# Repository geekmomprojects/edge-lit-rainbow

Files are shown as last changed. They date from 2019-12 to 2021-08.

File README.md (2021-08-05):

# Edge-Lit Rainbow
Updated code and design files for Edge Lit Rainbow project in Make: Vol. 69

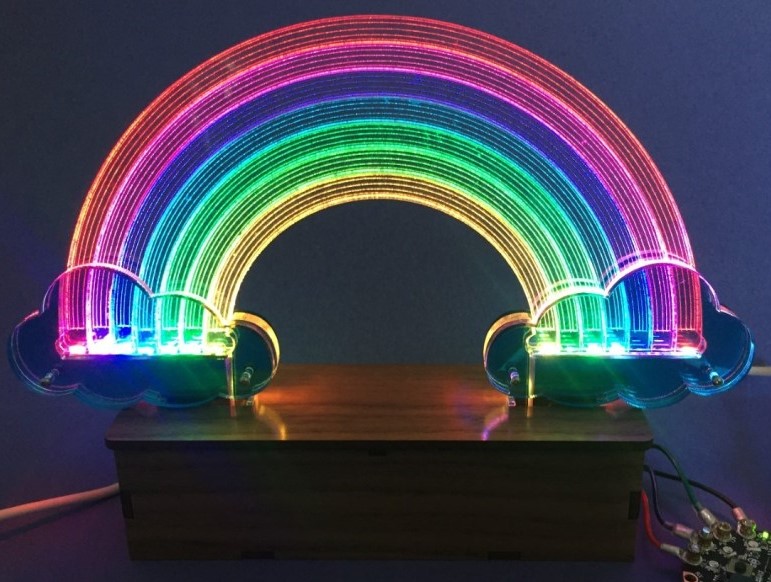
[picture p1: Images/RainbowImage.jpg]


When connected to WiFi and running the included Arduino code, the controller can connect to OpenWeatherMap to retrieve current temperature and weather conditions. If the conditions are sucessfully downloaded, every 30 seconds, the rainbow will display a solid color that maps to the current temperature, using the spectrum shown below:



The original instructions connected the rainbow to an Adafruit Huzzah ESP8266 microcontroller as shown below:

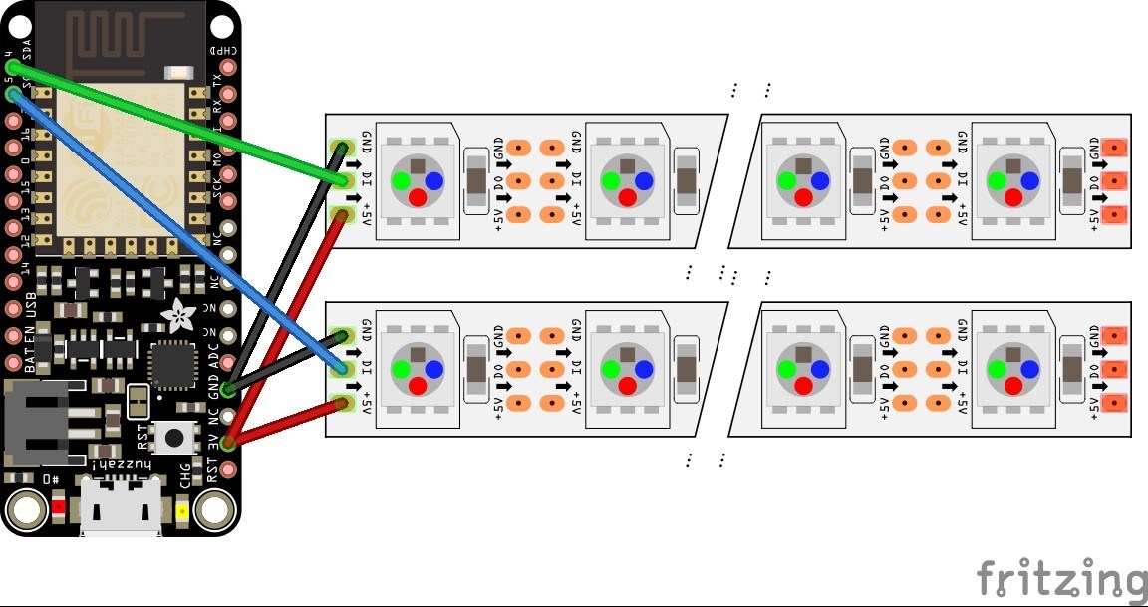
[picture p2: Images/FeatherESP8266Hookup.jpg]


The rainbow may now be connected to an ESP32 or ESP8266 controller, with an optional push button to allow it to enter configuration mode:

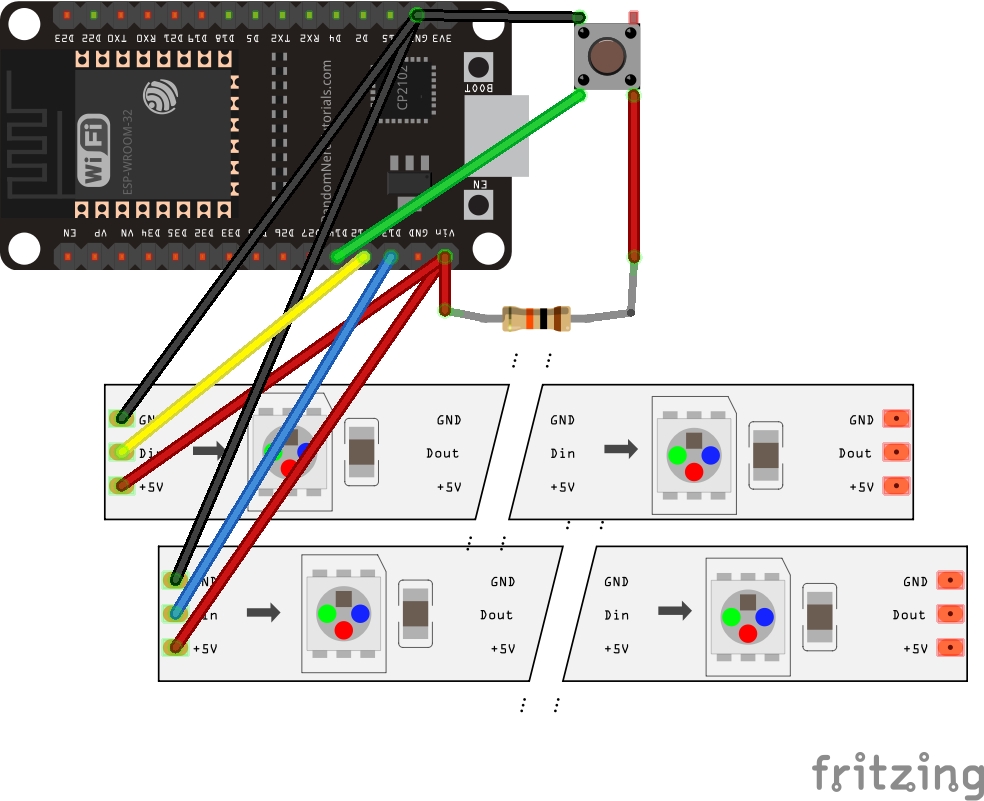
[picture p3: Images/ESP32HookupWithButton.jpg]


CircuitPython code is also included to allow the Rainbow to be connected to an Adafruit Circuit Playground Express in an interactive mode:

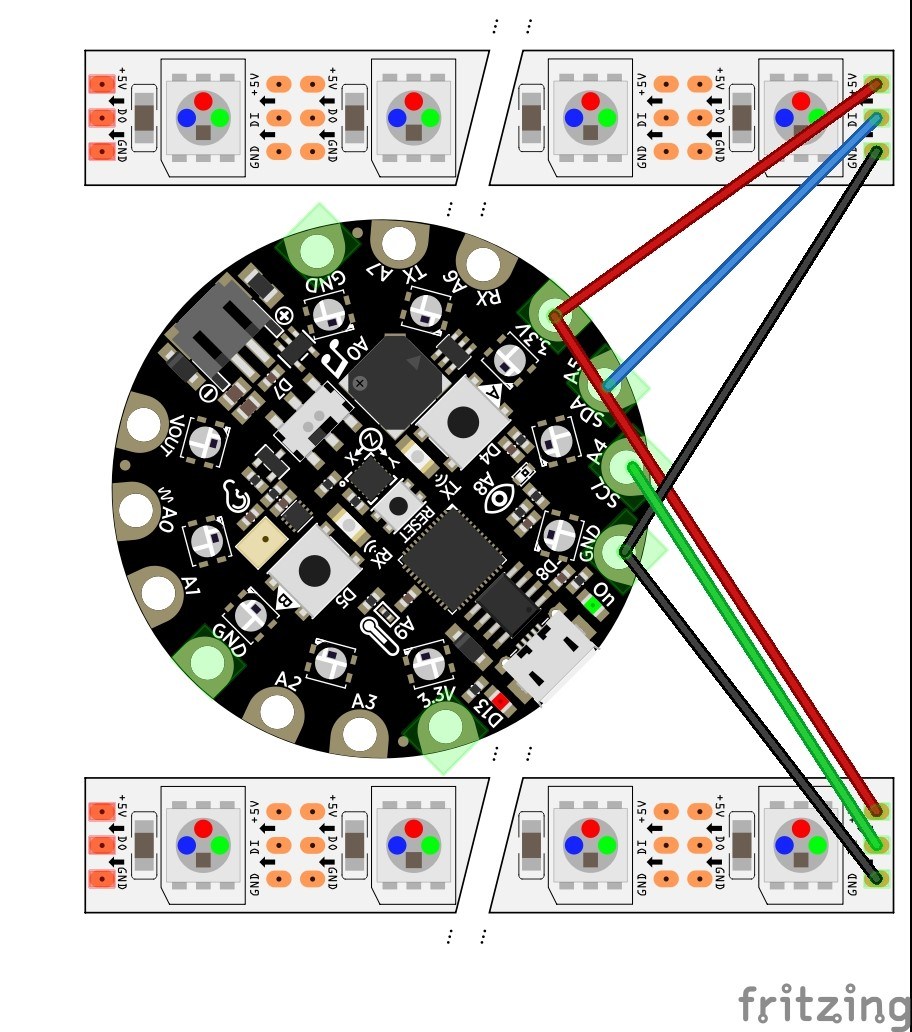
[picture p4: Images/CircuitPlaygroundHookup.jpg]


# Configuration Mode

While it is attempting to connect to WiFi, the rainbow will cycle through lighting up each arc until it has successfully connected or until it enters configuration mode. If it connects successfully, it will display cycling rainbow pattern. When it enters configuration mode, all arcs of the rainbow will pulse red until the WiFi connection is configured, or until 90 seconds has passed. After 90 seconds, the normal rainbow pattern will start to display.

When running on an ESP32 or ESP8266 with the supplied Arduino code, the rainbow will enter configuration mode automatically on startup if it cannot connect to WiFi, either because it doesn't have stored SSID/Password or because the stored SSID/Password don't connect. You can also force the ESP into configuration mode at startup by grounding the button pin (easiest if you physically connect a button to the pin).

Once it is in configuration mode, you can configure the connection parameters by connecting to the local access point named "RainbowConnection". 

Currently, you may find additional information about configuring the connection parameters here: <a href="http://brightwearables.com/rainbowconnect/">http://brightwearables.com/rainbowconnect/</a>

# Update - July 19, 2020

The following changes have been added to the Arduino code:
- The code now runs on ESP32 as well as ESP8266 boards
- Code is added to support an optional push putton which starts the program in "Configuration Mode". In Configuration mode, the ESP board boots as a WiFi access point named "RainbowConnection". Logging int access point allows the user to configure the board to connect to local WiFi.
- The OpenWeatherMap LocationID and AppID are stored in spiffs and can be set through the Access Point when the ESP is in Configuration Mode

# Update - August 6, 2021

The code has been streamlined a bit and successfully tested on both an ESP8266 and ESP32
- The Arduino code has been reconfigured to remove any dependence on external OpenWeatherMap access libraries, and the Arduino sketch is now contained in a single file.
- The Arduino library dependencies have changed. See the comments at the top of the sketch to find which libraries you will need for your board
- The pin for the LED strips and buttons have changed. Look for the variables LED_PIN_LEFT, LED_PIN_RIGHT and BUTTON_PIN to find/change their values

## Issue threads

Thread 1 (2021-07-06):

Finding Libraries?

gallaugher, 2021-07-06:
Sorry to trouble you. I must be missing something basic. Am running on an Adafruit Huzzah32, and "Adafruit ESP32 Feather" is installed & serial port seems to be recognized properly. Am using Arduino IDE 1.8.15.

Comments list the libraries that are required & that can be found in the Arduino Library Manager, but I can't seem to locate:
**ESP8266WiFi**, **ESP8266HTTPClient**, and **JsonListener**.
Is there an Additional Board Manager URL I need to enter to find these, or am I skipping another key step?

When I run & compile (noting I haven't installed the three libraries above), I get the error:
**LITTLEFS.h: No such file or directory**
Found "LittleFS_esp32" in Arduino Library Manager, installed that, the error above went away, but then encountered:
**"ESP8266WebServer.h: No such file or directory"**
When searching "ESP8266WebServer" under basic Arduino Library Manager configuration, five libraries come up, but none are named "ESP8266WebServer".

API key & location should be properly set once these issues are resolved. Thanks for your work on this great project & for taking the time to respond.

geekmomprojects, 2021-07-06:
Hi,

Sorry it’s causing you difficulty. The ESP8266WiFi & ESP8266HTTPClient, should show up if you have the following in your Additional Manager URLs: http://arduino.esp8266.com/stable/package_esp8266com_index.json. Hopefully that will solve your ESP8266WebServer issues as well.

The JSON listener library is in the library manager if you filter the “Manage Libraries” window with “json streaming parser”.

Let me know if you’re still having problems.

Best,
Debra

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

gallaugher, 2021-07-07:
Thanks for your kind response & your great work. I think I've hunted down some additional steps that will make things work on the Huzzah32. Detailed what I did below, but you know WAY more about Arduino than I do, and this is your brilliant creation, so apologies if I've got something wrong & just goofed.

For some reason, when I added the URL in Arduino preferences:
http://arduino.esp8266.com/stable/package_esp8266com_index.json
I still couldn't find the esp8266 in Manage Libraries...
Wasn't sure this is what I needed for the the Huzzah32, but I found that I could comment out:
  #include <ESP8266WebServer.h>
and replace this with
  #include <WebServer.h>
and when I ran this, I was able to get everything to work except the LEDs: Rainbow Connection allowed setup to my local WiFi, then in the Serial Monitor I saw proper fetching & printing weather for my location.
unfortunately my LEDs weren't showing. Since they were working with the CPX (I used your tip on soldering the JST connectors for quick swap-out. Great advice - I bought a bunch of connectors to do this in future projects), I thought I had a soldering / wire problem on the Huzzah32 side. But I saw this wasn't the case when I broke out an old Huzzah (the older 8266) and wrote a simple sketch which I thought would light up the strips. Struggled to figure out why code on the other board wasn't working, then consulted the pinouts & saw they were different! Changing the LED_PIN_RIGHT & _LEFT seems to have fixed this. I think this is because the SDA and SCL pins are different numbers on those two boards.

Sorry I didn't take better notes when trouble-shooting, but I *think* this is what works for to get the project to function on a Huzzah32:

Use WebServer.h instead of ESP8266WebServer.h (which I *think* is in ESP_WiFiManager, which I found & added when searching for Libraries in the Arduino's "Manager Libraries...").
> Commented out: #include <ESP8266WebServer.h>
> Replaced with: #include <WebServer.h> // all other code related to these libraries seemed to work w/o additional modification.

Replace the LED_PIN values to conform to Huzzah32
> #define LED_PIN_RIGHT 23 // <- pin for SDA on Huzzah32
> #define LED_PIN_LEFT 22 // <- pin for SCL on Huzzah32

I may have also had to track down some additional libraries at other points. I was struggling to find LittleFS, but eventually found it. I have FS and LittleFS_esp32 in my Include Library menu. Again, sorry I didn't take better notes during the troubleshooting.

Also: I tried running the updated RainbowWeatherStation code on an older Huzzah with the 8266, but it failed when hitting the first line:
#include <vfs_api.h>
Unsure if this is something specific to ESP32. I didn't go back & try to re-work the code & fully wire the 8266, but maybe just drop that in the if block where you check if the ESP32 is running?

Finally - am I correct in assuming whenever the build is powered down that Wi-Fi needs to b re-set? When I moved from Huzzah connected to my Mac to a separate power connection for the build, I needed to re-establish Wi-Fi with Rainbow connection despite being on the same WiFi network. My assumption based on this is that there's no flash storage or code to save these parameters on the Huzzah32. Didn't go through the code to see if code is, in fact, there & it's just not working on Huzzah32.

While I definitely struggled getting all this to work, that process is good for me since if I run into problems before my students, hopefully I can guide them through a solution having seen this before. I now know to check pinouts & not assume SCL SDA pins have the same numbers on different boards (sound like I'm diagnosing this right?). Your project really is a beautiful build. Thanks for putting this together & sharing your work!
John

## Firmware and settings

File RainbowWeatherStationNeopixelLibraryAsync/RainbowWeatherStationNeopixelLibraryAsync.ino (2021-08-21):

/************************************************************************************
 * The RainbowWeatherStation sketch is adapted from Adafruit's esp8266 weather station 
 * (https://github.com/adafruit/esp8266-weather-station-color) which, in turn, was adapted
 * from ThingPulse's WiFi Color Display Kit (https://docs.thingpulse.com/guides/wifi-color-display-kit/)
 * 
 *                      ************ Required Libraries ************
 *                      
 * The following libraries are required for this application, and are available through the Arduino
 * library manager, regardless of which board you use:
 * 
 *      ESPAsyncTCP.h>           //https://github.com/me-no-dev/AsyncTCP/archive/master.zip
 *      ESPAsyncWebServer.h      // https://github.com/me-no-dev/ESPAsyncWebServer/archive/master.zip
 *      ESPAsyncWiFiManager.h    //https://github.com/alanswx/ESPAsyncWiFiManager/
 *      Adafruit_NeoPixel
 *      ArduinoJson             // v6.0
 *      Ticker                  // The version explicitly for esp8266
 *    
 * The following libraries are specific to the platform you are running the code on:
 * Running on ESP8266 (e.g. Adafruit HUZZAH, Wemos D1 mini): 
 * 
 *      ESP8266WiFi
 *      ESP8266HTTPClient
 *      
 * Running on ESP32 (e.g. DEVKIT V1 or Adafruit HUZZAH32)
 * 
 *      WiFi
 *      HTTPClient
 *      
 *     ************ Getting Weather Information from Open Weather Map ************
 *
 * UPDATE - July 19, 2020. You can now set the Open Weather Map App ID and Location ID in the code
 * directly, or you can set them through the WiFi Manager. They are stored in SPIFFS as WiFiManager
 * custom parameters
 *
 * This code relies on data from OpenWeatherMap (https://openweathermap.org/), a free 
 * online weather service with an easily accessible API. 
 * 
 * To run the RainbowWeatherStation code on your own ESP8266, you must find and set the following two 
 * variables to values you obtain from OpenWeatherMap:
 * 
 * (1) OPEN_WEATHER_MAP_APP_ID - Get an app id by signing up and following the directions from
 * ThingPulse: https://docs.thingpulse.com/how-tos/openweathermap-key/
 * 
 * (2) OPEN_WEATHER_MAP_LOCATION_ID - Go to https://openweathermap.org/find?q= and search for a 
 * location. Go through the result set and select the entry closest to the actual location you want 
 * to display data for. It'll be a URL like https://openweathermap.org/city/2657896. Select the 
 * numbers that form the last part of the URL and assign them to the variable.
 * 
 *    ************ Establishing an Internet Connection with WiFiManager ************
 * 
 * This code uses the WiFiManager library (https://github.com/tzapu/WiFiManager) to manage WiFi connections, 
 * so there is no need to store an SSID/Password in the code directly. When the RainbowWeatherStation code
 * starts running on an ESP8266, the WiFiManager will connect to the last succesfully connected Access Point. 
 * You will see the arcs of the rainbow scrolling in yellow while it is establishing the connection.
 * 
 * If the ESP8266 is unable to connect to the WiFi, the rainbow will flash on and off in red, indicating
 * that your input is needed. WiFiManager creates it's own access point called "RainbowConnection". Connect
 * any WiFi enabled device to the "RainbowConnection" access point, and open a browser. You will be directed
 * to a popup or website that asks you to enter a network SSID and password. These values will be saved
 * on the ESP8266 for the next time you run the code.
 * 
 * 
 *   ************ Interpreting the Weather Display ************
 *    
 *   OpenWeatherMap limits the frequency of calls to its API, so the code checks the weather every
 *   12 minutes. The weather conditions will only start to display after the first successful call 
 *   to the OpenWeatherMap API. Therefore no weather conditions will be displayed for the first 12 
 *   minutes after plugging in the WeatherStationRainbow. If you'd like to simulate particular weather
 *   conditions to see what the display looks like, look for the commented code that says 
 *   "simulate particular weather conditions."
 *    
 *   The Rainbow Weather Station displays a rotating color spectrum on the rainbow arcs.
 *   The rainbow display lasts 30 seconds (you can change this value in the array "animDurations")
 *   When the rainbow animation ends, the rainbow colors will fade into a single solid color which
 *   represents the current temperature. The mapping of the temperature to the rainbow spectrum
 *   is shown in the image "TemperatureSpectrum.png"
 
 *   If the weather forecast calls for high winds, rain, or snow, additional animations will run
 *   after the temperature is displayed. The rainbow will remain the color representing the current
 *   temperature but will exhibit the following patterns:
 *   
 *   High Wind - The intensity of the color will increase and dim on each side alternately
 *   Rain - Raindrops (arcs where the LEDs are dimmed) will drip down the rainbow
 *   Snow - The rainbow arcs will display periodic white flashes to represent snowflakes
 *   
 *   Each of these weather animations will last for about 5 seconds. The duration is specified in the
 *   array "animDurations", which you can change if you'd like.
 * 
*************************************************************************************/


/**The MIT License (MIT)

Copyright (c) 2018 by Daniel Eichhorn - ThingPulse

Permission is hereby granted, free of charge, to any person obtaining a copy
of this software and associated documentation files (the "Software"), to deal
in the Software without restriction, including without limitation the rights
to use, copy, modify, merge, publish, distribute, sublicense, and/or sell
copies of the Software, and to permit persons to whom the Software is
furnished to do so, subject to the following conditions:

The above copyright notice and this permission notice shall be included in all
copies or substantial portions of the Software.

THE SOFTWARE IS PROVIDED "AS IS", WITHOUT WARRANTY OF ANY KIND, EXPRESS OR
IMPLIED, INCLUDING BUT NOT LIMITED TO THE WARRANTIES OF MERCHANTABILITY,
FITNESS FOR A PARTICULAR PURPOSE AND NONINFRINGEMENT. IN NO EVENT SHALL THE
AUTHORS OR COPYRIGHT HOLDERS BE LIABLE FOR ANY CLAIM, DAMAGES OR OTHER
LIABILITY, WHETHER IN AN ACTION OF CONTRACT, TORT OR OTHERWISE, ARISING FROM,
OUT OF OR IN CONNECTION WITH THE SOFTWARE OR THE USE OR OTHER DEALINGS IN THE
SOFTWARE.

See more at https://thingpulse.com
*/
#ifdef ESP32    
  #include <FS.h> // needs to be the first include or it all breaks
#endif
#include <Arduino.h>
  
#define USE_LittleFS
#ifdef USE_LittleFS
  #define SPIFFS LittleFS
  #include <LittleFS.h> 
#else
  #include <SPIFFS.h>
#endif 

#ifdef ESP32
  #include <WiFi.h>
  #include <HTTPClient.h>
#endif

#ifdef ESP8266
  #include <ESP8266WiFi.h>
  #include <ESP8266HTTPClient.h>
#endif


#include <DNSServer.h>            //Local DNS Server used for redirecting all requests to the configuration portal

// You have to explicitly specify false to disable the feature.
#define USE_STATIC_IP_CONFIG_IN_CP          false
#include <ESPAsyncTCP.h>            //https://github.com/me-no-dev/AsyncTCP/archive/master.zip
#include <ESPAsyncWebServer.h>     // https://github.com/me-no-dev/ESPAsyncWebServer/archive/master.zip
#include <ESPAsyncWiFiManager.h>  //https://github.com/alanswx/ESPAsyncWiFiManager/

#include <ArduinoJson.h>

// Ticker class runs callback functions at set intervals
#include <Ticker.h>

//Neopixel library - testing Adafruit Neopixel because FastLED seems to conflict with ESP8266 WiFi
#include <Adafruit_NeoPixel.h>


#ifdef __AVR__
  #include <avr/power.h>
#endif
#define LED_PIN_LEFT       13  //13 on Lolin, 19 on DevKit, 12 on Wemos D1 Mini, 
#define LED_PIN_RIGHT      12  //12 on Lolin, 18 on DevKit, 14 on Wemos D1 Mini, 

#define NUM_LEDS_PER_STRIP  7
#define RAINBOW_INCREMENT   // Hue increment between arcs of the rainbow

// Two separate LED strips for left/right sides of rainbow
Adafruit_NeoPixel left(NUM_LEDS_PER_STRIP, LED_PIN_LEFT, NEO_GRB + NEO_KHZ800);
Adafruit_NeoPixel right(NUM_LEDS_PER_STRIP, LED_PIN_RIGHT, NEO_GRB + NEO_KHZ800);

// The Feather ESP8266 recommends keeping current draw from the regulator under 250 mA.
// The rainbow contains 14 SK6812 3535 LEDs.  With a max of 40mA per LED  => 560mA. 
// Setting brightness to 50% will work
#define BRIGHTNESS          128

// Add optional button to force the ESP board into config mode at startup
// comment out the following line
//#define HAS_BUTTON
#ifdef HAS_BUTTON
  #define BUTTON_PIN 14  // 23 on DevKit, 14 on Lolin, 13 on Wemos D1 Mini,
#endif

const char*   AP_STATION_NAME = "RainbowConnection";
String        weatherQuery, jsonBuffer;
boolean       bHaveQueryData = false;

// Used to parse query
StaticJsonDocument<2048> jsonWeather;

/***************************
 * Begin Settings
 **************************/

// Setup
const int WEATHER_UPDATE_INTERVAL_SECS = 12*60;  // Update weather reading every 12 minutes

// OpenWeatherMap Settings
// Sign up here to get an API key:
// https://docs.thingpulse.com/how-tos/openweathermap-key/
String OPEN_WEATHER_MAP_APP_ID = "WeatherMapID";

/*
Go to https://openweathermap.org/find?q= and search for a location. Go through the
result set and select the entry closest to the actual location you want to display 
data for. It'll be a URL like https://openweathermap.org/city/2657896. The number
at the end is what you assign to the constant below.
 */

String OPEN_WEATHER_MAP_LOCATION_ID = "LocationID"; 
//String OPEN_WEATHER_MAP_LOCATION_ID = "5368361"; // Westwood, CA
//

// Pick a language code from this list:
// Arabic - ar, Bulgarian - bg, Catalan - ca, Czech - cz, German - de, Greek - el,
// English - en, Persian (Farsi) - fa, Finnish - fi, French - fr, Galician - gl,
// Croatian - hr, Hungarian - hu, Italian - it, Japanese - ja, Korean - kr,
// Latvian - la, Lithuanian - lt, Macedonian - mk, Dutch - nl, Polish - pl,
// Portuguese - pt, Romanian - ro, Russian - ru, Swedish - se, Slovak - sk,
// Slovenian - sl, Spanish - es, Turkish - tr, Ukrainian - ua, Vietnamese - vi,
// Chinese Simplified - zh_cn, Chinese Traditional - zh_tw.
String OPEN_WEATHER_MAP_LANGUAGE = "en";
const boolean IS_METRIC = false;

/***************************
 * End Settings
 **************************/



boolean doSaveConfig = false;

//callback notifying us of the need to save config
void saveConfigCallback () {
  Serial.println("Should save config");
  doSaveConfig = true;
}

#define WIND_SPEED_THRESHOLD 15  //mph - considered "windy" over this value
float     currentTemperature = 70.0; // Fahrenheit, b/c I live in the US
uint32_t  curTempColor = 0xffffff;

// Indicates whether the last call to check the weather information returned a value
boolean bTemperature = false;
boolean bWind = false;
boolean bRain = false;
boolean bSnow = false;

boolean bDisplayTemperature = false;
boolean bDisplayWind = false;
boolean bDisplayRain = false;
boolean bDisplaySnow = false;
boolean bInitializeTemperatureAnimation = true;
boolean bInitializeRainbowAnimation = true;
boolean bCheckWeather = false;
boolean bUpdateLeds = false;


enum animEnums{RAINBOW, TEMPERATURE, WIND, RAIN, SNOW, TICK, FLASH, NUM_ANIMS};
#define MAX_ANIMATIONS  10

Ticker    firstWeatherCheckTicker;
Ticker    weatherCheckTicker;
Ticker    hueTicker;
Ticker    animTicker;
Ticker    advanceAnimTicker;
int       gCurrentAnimation = RAINBOW;
uint16_t  gHue = 0; // rotating "base color" for rainbow patterns

typedef void (*AnimationFunction)();

struct AnimFunction {
      AnimationFunction func;     // function pointer
      float             duration; // runningTime in seconds
      uint16_t          rate_ms;  // interval between callbacks in ms  
} allAnims[MAX_ANIMATIONS];

void   startAnimation(uint8_t index, AnimationFunction animationAdvanceFunc = NULL) {
  animTicker.detach();
  gCurrentAnimation = index;
  animTicker.attach_ms(allAnims[index].rate_ms, allAnims[index].func);
  if (animationAdvanceFunc != NULL) {
    // Setup next function changeover
    advanceAnimTicker.once(allAnims[index].duration, animationAdvanceFunc); 
   }
}

void stopAllAnimations() {
  animTicker.detach();
  gCurrentAnimation = -1;
}

void setAnimation(uint8_t index, void (*animationFunction)(), float d, uint16_t r) {
  allAnims[index].func = animationFunction;
  allAnims[index].duration = d;
  allAnims[index].rate_ms = r;
}

#define RAINBOW_MS 20
#define TEMP_MS    30

// This function gets called in setup
void initializeAnimations() {
  // Setting animation function, duration(sec) , frequency(ms)
  setAnimation(RAINBOW, rainbow, 30, RAINBOW_MS); 
  setAnimation(TEMPERATURE, temperatureAnimation, 4, TEMP_MS);
  setAnimation(WIND, windAnimation, 5, 30);  
  setAnimation(RAIN, rainAnimation, 5, 30);
  setAnimation(SNOW, snowAnimation, 5, 30);
  setAnimation(TICK, tickAnimation, 0, 80);   //no set duration
  setAnimation(FLASH, flashAnimation, 0, 30); //no set duration
}




// Endpoints of displayed temperature range (Fahrenheit) which is mapped to the gradient palette below
float tempRange[2] = {-20.0, 120.0};

// Regularly spaced colors define a linear temperature gradient palette. 
// Taken from http://soliton.vm.bytemark.co.uk/pub/cpt-city/arendal/tn/temperature.png.index.html
#define N_COLOR_INTERVALS 18
uint8_t colorIntervalValues[N_COLOR_INTERVALS][3] = {{1,27,105},{1,40,127},{1,70,168},{1,92,197},{1,119,221},{3,130,151},
                                                     {23,156,149},{67,182,112},{121,201,52},{142,203,11},{224,223,1},{252,187,2},
                                                     {247,147,1},{237, 87,1},{229,43,1},{220,15,1},{171,2,2},{80,3,3}};
// Same color intervals in 32 bit format
uint32_t colorIntervals[N_COLOR_INTERVALS] = {72553, 75903, 83624, 89285, 96221, 230039, 
                                              1547413, 4437616, 7981364, 9358091, 14737153, 16562946, 
                                              16225025, 15554305, 15018753, 14421761, 11207170, 5243651};

// Helper function that generates 32 bit values from color intervals array
void fillColorIntervals() {
  Serial.print("{");
  for(int i = 0; i < N_COLOR_INTERVALS; i++) {
    colorIntervals[i] = left.Color(colorIntervalValues[i][0], colorIntervalValues[i][1], colorIntervalValues[i][2]);
    Serial.print(colorIntervals[i]);
    Serial.print(", ");
  }
  Serial.println("}");
}

// Unpacks 32-bit color into RGB (assuming no brightness correction                         
void getRGB(uint32_t col, uint8_t &R, uint8_t &G, uint8_t &B) {
  R = (uint8_t) (col >> 16 & 0xFF);
  G = (uint8_t) (col >> 8 & 0xFF);
  B = (uint8_t) (col & 0xFF);
}

// blends two 32-bit colors
uint32_t blendColor(uint32_t colSource, uint32_t colDest, int fraction) {
  uint8_t r1, g1, b1, r2, g2, b2;
  uint32_t newColor;
  
  getRGB(colSource, r1, g1, b1);
  getRGB(colDest, r2, g2, b2);
  newColor = left.Color((uint8_t) (r1 + ((r2 - r1)*fraction)/255),
                        (uint8_t) (g1 + ((g2 - g1)*fraction)/255),
                        (uint8_t) (b1 + ((b2 - b1)*fraction)/255));
  return newColor;
}

// Linearly interpolate between the colorIntervals to connvert specified temperature to a color
uint32_t tempToColor(float temp) {
  temp = constrain(temp, tempRange[0], tempRange[1]);
  float intervalSize = (tempRange[1] - tempRange[0])/(N_COLOR_INTERVALS-1);
  int interval = (int) ((temp - tempRange[0])/intervalSize);
  uint8_t pos = (int) (255*(temp - interval*intervalSize)/intervalSize);
  uint32_t col = blendColor(colorIntervals[interval], colorIntervals[interval + 1], pos);
  return col;
}

//Calls show() on both LED strips
void showAll() {
  left.show();
  right.show();
}

// Fills both sides with a solid color
void fillSolid(uint32_t col) {
  left.fill(col, 0, NUM_LEDS_PER_STRIP);
  right.fill(col, 0, NUM_LEDS_PER_STRIP);
}

// Arcs labelled 0-6 from inside to outside
void fillArc(uint32_t col, uint8_t arc) {
  left.setPixelColor(arc, col);
  right.setPixelColor(arc, col);
}

// Moves color around the arcs while ESP8266 searches for a wifi connection
void tickAnimation() {
  const int hue = 0;
  static uint8_t arc = 0;
  uint32_t col = Adafruit_NeoPixel::ColorHSV(hue, 255, 255);
  fillSolid(0);
  fillArc(col, arc);
  arc = (arc + 1) % NUM_LEDS_PER_STRIP;
  showAll();
}


uint8_t sin8bit( uint8_t t ) {
  return (uint8_t) Adafruit_NeoPixel::sine8(t);
}

// Dims and brightens the rainbow in the specified hue
void flashAnimation() {
  const int hue = 30;
  static uint8_t nFrames = 0;
  uint8_t val = sin8bit(nFrames);
  uint32_t col = Adafruit_NeoPixel::ColorHSV(hue, 255, val); 
  fillSolid(col);
  showAll();
  nFrames = (nFrames + 2)%255;
}

AsyncWebServer server(80);
const char* PARAM_INPUT_1 = "input1";
const char* PARAM_INPUT_2 = "input2";

// HTML web page to handle 3 input fields (input1, input2, input3)
const char index_html[] PROGMEM = R"rawliteral(
<!DOCTYPE HTML><html><head>
  <title>ESP Input Form</title>
  <meta name="viewport" content="width=device-width, initial-scale=1">
  </head><body>
  <form action="/get">
    Location ID: <input type="text" name="input1">
    <input type="submit" value="Submit">
  </form><br>
  <form action="/get">
    API Key: <input type="text" name="input2">
    <input type="submit" value="Submit">
  </form><br>
</body></html>)rawliteral";

void notFound(AsyncWebServerRequest *request) {
  request->send(404, "text/plain", "Not found");
}


void startWebServer() {
  if (WiFi.status() != WL_CONNECTED) {
    Serial.println("in start web server not connected");
  } else {
     Serial.print("IP Address: ");
    Serial.println(WiFi.localIP());
  }
  // Send web page with input fields to client
  server.on("/", HTTP_GET, [](AsyncWebServerRequest *request){
    request->send_P(200, "text/html", index_html);
  });

  // Send a GET request to <ESP_IP>/get?input1=<inputMessage>
  server.on("/get", HTTP_GET, [] (AsyncWebServerRequest *request) {
    String inputMessage;
    String inputParam;
    // GET input1 value on <ESP_IP>/get?input1=<inputMessage>
    if (request->hasParam(PARAM_INPUT_1)) {
      inputMessage = request->getParam(PARAM_INPUT_1)->value();
      inputParam = PARAM_INPUT_1;
    }
    // GET input2 value on <ESP_IP>/get?input2=<inputMessage>
    else if (request->hasParam(PARAM_INPUT_2)) {
      inputMessage = request->getParam(PARAM_INPUT_2)->value();
      inputParam = PARAM_INPUT_2;
    }
    else {
      inputMessage = "No message sent";
      inputParam = "none";
    }

    Serial.println(inputMessage);
    request->send(200, "text/html", "HTTP GET request sent to your ESP on input field (" 
                                     + inputParam + ") with value: " + inputMessage +
                                     "<br><a href=\"/\">Return to Home Page</a>");
    if (inputParam == PARAM_INPUT_1) {
      saveOWMParams(inputMessage.c_str(), OPEN_WEATHER_MAP_APP_ID.c_str());
      OPEN_WEATHER_MAP_LOCATION_ID = inputMessage;
    } else if (inputParam == PARAM_INPUT_2) {
      saveOWMParams(OPEN_WEATHER_MAP_LOCATION_ID.c_str(), inputMessage.c_str());
      OPEN_WEATHER_MAP_APP_ID = inputMessage;
    }
  });
  server.onNotFound(notFound);
  server.begin();
}
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
void loop() {
  if (bUpdateLeds) {
    showAll();
    bUpdateLeds = false;
  }
  if (bCheckWeather) {
    checkWeather();
    bCheckWeather = false;
  }
}

void setCheckWeather() {
  bCheckWeather = true;
}

// Send web query
String httpGETRequest(const char* serverName) {
  WiFiClient client;
  HTTPClient http;
  
  // Your IP address with path or Domain name with URL path 
  http.begin(client, serverName);
  
  // Send HTTP POST request
  int httpResponseCode = http.GET();
  String payload = "{}"; 
  
  if (httpResponseCode>0) {
    Serial.print("HTTP Response code: ");
    Serial.println(httpResponseCode);
    payload = http.getString();
  }
  else {
    Serial.print("Error code: ");
    Serial.println(httpResponseCode);
    Serial.println(http.errorToString(httpResponseCode).c_str());
  }
  // Free resources
  http.end();
  return payload;
}

// Pull weather data from openWeatherMap and update the stored current weather conditions and temperature
void updateData() {
  weatherQuery = "http://api.openweathermap.org/data/2.5/weather?id=" + OPEN_WEATHER_MAP_LOCATION_ID + "&appid=" + OPEN_WEATHER_MAP_APP_ID + "&units=imperial";
  Serial.print("Query: ");
  Serial.println(weatherQuery);
  jsonBuffer = httpGETRequest(weatherQuery.c_str());
  Serial.println(jsonBuffer);

  DeserializationError error = deserializeJson(jsonWeather, jsonBuffer.c_str());
  if (error) {
    Serial.print(F("deserializeJson() failed: "));
    Serial.println(error.f_str());
    return;
  }

  // Check response code to see if query succeeded
  int responseCode = jsonWeather["cod"];
  if ((int) (responseCode / 100) != 2) {  // Code response should be 2XX for success
    Serial.print(F("Response code request failed. Code: "));
    Serial.println(responseCode);
    return;
  }
  
  // Update temperature
  bTemperature = true;
  currentTemperature = jsonWeather["main"]["temp"];
  if (currentTemperature) {
    curTempColor = tempToColor(currentTemperature);
    bTemperature = true;
    Serial.print("Current temperature: ");
    Serial.println(currentTemperature);
  }

  // Parse windspeed
  float windSpeed = jsonWeather["wind"]["speed"];
  Serial.print("Wind speed: ");
  Serial.println(windSpeed);
  bWind = (windSpeed > WIND_SPEED_THRESHOLD) ? true : false;

  // Check weather description for rain or snow
  String mainWeather = jsonWeather["weather"][0]["main"];
  Serial.print("Main: ");
  Serial.println(mainWeather);
  mainWeather.toLowerCase();
  bSnow = (mainWeather.indexOf("snow") >= 0) ? true : false;
  bRain = (mainWeather.indexOf("rain") >= 0) ? true : false;
}

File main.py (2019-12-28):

import board
import neopixel
from time import sleep
import adafruit_fancyled.adafruit_fancyled as fancy
from adafruit_circuitplayground.express import cpx

PIX_PER_STRIP = 7

#If true, color stripes alternate in interactive mode
COLORS_ALTERNATING = True

#Set brightnessto 1, we'll use gamma adjustment for brightness control
strip1 = neopixel.NeoPixel(board.D2, PIX_PER_STRIP, brightness=1, auto_write=False)
strip2 = neopixel.NeoPixel(board.D3, PIX_PER_STRIP, brightness=1, auto_write=False)

# BaseHue is an evolvoing hue value, allowing colors to drift
# across the sprectrum with time. FancyLED accepts any real number
# to specify hue, but only the decimal portion matters
baseHue = .86
hueInc = -0.003
hueSpeed = 3
maxHueSpeed = 8

# Specfies the difference in hue between adjacent rainbow arcs.
# the value is < 0 because longest wavelengths are on the outside
arcHueInc = -0.14

# Set the rate at which the baseHue evolves
def incrementHueSpeed():
  global hueSpeed
  hueSpeed = hueSpeed + 2
  if hueSpeed > maxHueSpeed:
    hueSpeed = 1
    
# Increments the baseHue
def incrementHue():
  global baseHue
  baseHue += hueInc*hueSpeed

#Turn all LEDs off
def ledsOff():
  strip1.fill((0,0,0))
  strip2.fill((0,0,0))
  strip1.show()
  strip2.show()

#These brightness levels seem to help balance color by toning down blue and upping red,
#but there is no real quantitative rationale behind them
levels=(0.75,0.9,0.45)
def setRainbow(strip, startHue, inc):
    for j in range(PIX_PER_STRIP):
      col = fancy.gamma_adjust(fancy.CHSV(startHue),brightness=levels)
      strip[j] = col.pack()
      startHue += inc

def clamp(n, min, max):
  if n < min:
    return min
  elif n > max:
    return max
  else:
    return n

#Clamps acceleration value to g (hopefully ignore jitter) and scales it to [0,1.0]
def accelToRange(accel):
  accel = clamp(accel, -9.8, 9.8)
  return 0.5 + accel/(2*9.8)

# Multiply a tuple by a scalar
def multiplyTuple(factor, tup):
  return tuple([factor*x for x in tup])

# Track the state of the buttons (pressed=True, unpressed=False) for debouncing
buttonStateA = False
buttonStateB = False

# contrast is the difference in hue between the two sides of each 
# rainbow arc. If contrast is an integer, the hues are identical and
# if contrast is an odd multiple of 0.5, hues are color wheel opposites.
contrast = 0.0

while True:
  # Check for button presses
  
  # Button A increments the rate at which the hue changes.
  if not cpx.button_a and buttonStateA:
    incrementHueSpeed()
    buttonStateA = False
    #Flashing LEDs off makes it easier to see when we've pushed the button
    #because changing hue rotation speed isn't super obvious
    ledsOff()
  elif cpx.button_a and not buttonStateA:
    buttonStateA = True

  # Button B toggles between alternating and identical color modes
  if not cpx.button_b and buttonStateB:
    COLORS_ALTERNATING = not COLORS_ALTERNATING
    contrast += 0.5
    buttonStateB = False
  elif cpx.button_b and not buttonStateB:
    buttonStateB = True

  if cpx.switch:  # Spectrum mode
    setRainbow(strip1, baseHue, arcHueInc)
    setRainbow(strip2, baseHue+contrast, arcHueInc)

  else: # Color mixing mode
    # Change the relative brightness with side-to-side tilting of the CPX
    x, y, z = cpx.acceleration
    bright = accelToRange(x)

    # Set the relative brightness of the base color and its contrasting color
    col1 = fancy.gamma_adjust(fancy.CHSV(baseHue),brightness=multiplyTuple(bright,levels)).pack()
    col2 = fancy.gamma_adjust(fancy.CHSV(baseHue+0.5),brightness=multiplyTuple((1.0-bright),levels)).pack()
    if COLORS_ALTERNATING:  # Each rainbow side alternates colors
      colors = [col1,col2]
      index = 0
      for i in range(PIX_PER_STRIP):
        strip1[i] = colors[index]
        index = (index + 1) % 2
        strip2[i] = colors[index]
    else:  # Each rainbow side contains uniform color
      strip1.fill(col1)
      strip2.fill(col2)

  strip1.show()
  strip2.show()
  incrementHue()

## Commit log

2019-12-28 Added CircuitPython CPX code
2019-12-28 Added image files
    [CircuitPlaygroundHookup.fzz, FeatherHuzzahESP8266Hookup.fzz]
2020-07-18 Fixed symmetry issues and hole sizes in cloud files
    Fixed symmetry issues and hole sizes in cloud file
2020-07-18 Added ESP32 Compatibility and button for config on startup
    Code now works for both ESP32 and ESP8266. Added code to drop into config mode when a button, connected to BUTTON_PIN is pressed on startup
2020-07-20 Add Image CircuitPlaygroundHookup
2020-07-20 Fritzing file and image of ESP32 connection with button
    [ESP32HookupWithButton.fzz]
2021-08-05 Removed dependence on 3rd party libs
    Removed dependence on 3rd party OpenWeatherMap libraries, changed LED pins to 12/13, button pin to 14. Switched to different JSON parser library.
2021-08-12 Removed FastLED.delay() because it was causing problems
    [RainbowWeatherStation.ino, RainbowWeatherStationNeopixelLibrary.ino]
2021-08-12 Reversed the color sequence of hues in the rainbow to match real-world physics
    [RainbowWeatherStation.ino]
2021-08-20 Added NeoPixel - based library
    New Arduino code that works with NeoPixel library instead of FastLED. Uses "Ticker" class to call animation functions
